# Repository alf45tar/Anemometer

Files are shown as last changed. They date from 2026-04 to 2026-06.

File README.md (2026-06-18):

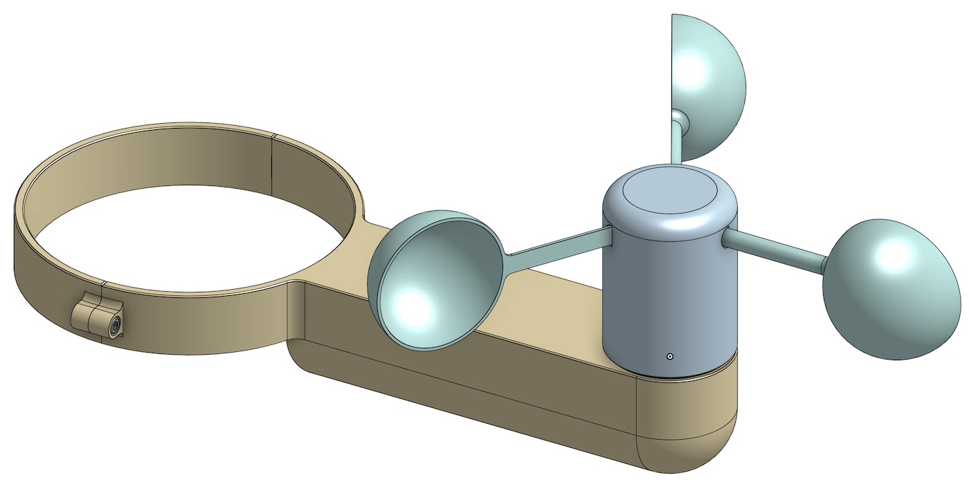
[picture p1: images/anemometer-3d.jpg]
3D Printed Anemometer


# 🌀 ESP32-C6 ULP BLE Anemometer (BTHome V2)

A high-efficiency, battery-powered wind speed sensor (Anemometer) using the ESP32-C6. This project leverages the **ULP (Ultra-Low Power) co-processor** to monitor wind pulses while the main CPU is in Deep Sleep, allowing for years of battery life.

The project uses the LP/ULP core to count anemometer pulses while the main CPU stays in deep sleep, then wakes periodically to compute wind speed and advertise telemetry over BLE using BTHome v2 format.

## 🚀 Key Features

* **Ultra-Low Power:** Can be as low as **\~15µA** in deep sleep on the ESP32-C6 alone. Actual current depends on the board and any attached hardware. The main cores only wake up to calculate and transmit data.
* **BTHome V2 Protocol:** Works natively with **Home Assistant** via Bluetooth—no custom integration or ESPHome YAML required. See [bthome.io](https://bthome.io).
* **Waterproof:** Designed to be waterproof for outdoor use.
* **Temperature Sensor:** Includes the ESP32-C6 internal temperature reading alongside wind speed and battery level telemetry.
* **Intelligent Reporting:**
  * **Wind Detected:** Typically reports on the next 5-second wake cycle while wind is present.
  * **Change Detection:** Tries to report a speed change as soon as it is noticed on the next wake cycle.
  * **Heartbeat:** Sends a periodic "still alive" update, usually about every 60 seconds during calm periods.
* **Hardware Debouncing:** ULP-based software sampling filters out mechanical reed switch "bounce."

## 🎓 What You Can Learn and Reuse in Your Projects

If you are building a similar low-power sensor, these patterns are practical to reuse:

* Keep the main CPU in deep sleep and let the LP/ULP RISC-V core handle pulse counting.
* Wake on a fixed interval, compute pulse delta and wind speed, then advertise only when needed.
* Use BTHome v2 so the sensor works directly with Home Assistant over BLE.
* Add a temperature reading to the same BLE payload so you can track the device environment without extra hardware.
* Add a heartbeat report so the device still publishes when conditions are calm.
* Filter reed-switch bounce in ULP software instead of relying only on hardware.
* Use RTC-capable GPIOs for ULP inputs on ESP32-C6, and avoid strapping pins.
* Add a capacitor across the battery sense divider to stabilize high-impedance ADC readings.
* Keep timing, calibration, BLE, and ADC values in a single header so they are easy to tune.
* Treat wind-speed calibration as a single empirical factor that can be adjusted without changing the rest of the flow.
* Preserve the PlatformIO + ESP-IDF setup and the debug/release sdkconfig defaults for repeatable builds.

## 🛠 Hardware Requirements

1. **ESP32-C6  Board** (e.g., ESP32-C6 Super Mini).
   * For ESP32 and ESP32-S3 boards, check the [ESP32/ESP32-S3](https://github.com/alf45tar/ESP32-ULP-BLE-Anemometer) anemometer project.
2. **Anemometer** (3-cup type with a Reed Switch).
3. **Battery:** Li-ion 18650 or LiPo.

### 📦 Bill of Materials

| Item | Quantity | Notes |
| :--- | :--- | :--- |
| ESP32-C6 Super Mini | 1 | Very cheap and low power board |
| 3D-printed anemometer | 1 | STL files for the [3D-printed parts](https://github.com/alf45tar/Anemometer/tree/main/stl) |
| 608 bearing 8x22x7 mm | 1 | Very common bearing for shaft support |
| M3 heat-set insert | 3 | For connecting the main body to the support and collar |
| M3 hex socket cap screw M3x10 | 3 | Fastens the main body to the support |
| Reed switch | 1 | Wind pulse sensor |
| Magnet 6x3 mm | 2 | For triggering the reed switch |
| O-Ring 8x2 mm | 1 | To seal the base of the rotor and the support |
| Battery | 1 | Li-ion 18650 or LiPo |
| Battery Holder | 1 | |

### 🔌 Wiring

Connect the reed switch between SENSOR_GPIO pin and GND (no need of external pull-up resistor because internal pull-up resistor is used).

```text
  SENSOR_PIN
      |
      |
      +  |
         +--- Reed switch
      +  |
      |
      |
     GND
```

For battery monitoring, a 470 kΩ resistor divider is required.
For stable ADC readings with high-value resistors, place a 0.1uF capacitor from ADC pin to GND.

```text
              BATTERY_ADC_GPIO
                     |
                     |
B+ -----/\/\/\/------+-----/\/\/\/-----+----- GND (B-)
         470k        |      470k       |
                     |                 |
                     +-------||--------+
                            0.1uF
                         (optional)
```

## 💻 Software Requirements

* PlatformIO
* ESP-IDF framework via PlatformIO (already defined in `platformio.ini`)

## 📡 Telemetry Format (BLE)

Advertising payload includes BTHome v2 service data with:

* Packet ID (object id `0x00`)
* Battery percentage (object id `0x01`)
* ESP32-C6 internal temperature in 0.01 °C units (object id `0x02`)
* Wind speed in 0.01 m/s units (object id `0x44`)

Device name in advertisement: `Wind Sensor`

Note: the temperature value is the ESP32-C6 internal chip temperature, not an ambient room sensor. Because the CPU spends most of its time in deep sleep, this reading is typically close to ambient. The internal temperature sensor is configured for a `-10` to `80` °C range.

## ⚙️ Key Tuning Constants

Edit `src/anemometer.h`:

```c
#define SENSOR_PIN 6                        // GPIO used for the anemometer pulse input
                                            // Must be RTC-capable pin: GPIO0-GPIO7 on ESP32-C6
                                            // Avoid GPIO4 and GPIO5 which are used for strapping
#define SLEEP_DURATION 5                    // Deep-sleep interval in seconds between wakeups
#define HEARTBEAT_INTERVAL 60               // Force a periodic telemetry heartbeat every N seconds
#define DEBOUNCE_INTERVAL_CYCLES 1000       // Minimum ULP clock cycles between valid edges to filter out noise (debouncing)

/* Anemometer conversion constants */
#define PULSES_PER_ROTATION 2.0f            // Sensor pulses generated for one full rotor rotation
#define RADIUS 0.078f                       // Rotor radius in meters (center to cup midpoint)
#define CALIBRATION_FACTOR 2.5f             // Empirical multiplier to match real wind speed

/* BLE/BTHome beacon behavior */
#define BLE_ADV_DURATION_MS 1000            // Advertising window duration after each wakeup
#define BLE_ADV_INTERVAL_UNITS 32           // BLE adv interval units (0.625 ms each): 32 = 20 ms

/* Battery measurement via ADC */
#define BATTERY_ADC_GPIO 0                  // GPIO connected to battery sense divider output
                                            // Must be an ADC-capable pin: GPIO0-GPIO6 on ESP32-C6
                                            // Avoid GPIO4 and GPIO5 which are used for strapping
#define BATTERY_ADC_SAMPLES 1               // Number of ADC readings averaged per measurement
#define BATTERY_VOLTAGE_DIVIDER_RATIO 2.0f  // Scale factor from ADC node voltage to battery voltage
#define BATTERY_MIN_MV 3200                 // Battery voltage mapped to 0%
#define BATTERY_MAX_MV 4100                 // Battery voltage mapped to 100%
```

## 🔄 How It Works

1. The main CPU enters deep sleep.
2. LP/ULP firmware monitors the sensor pin (`SENSOR_PIN`) and increments pulse count on valid rising edges.
3. Every wake interval (`SLEEP_DURATION`), the main CPU wakes up.
4. Firmware computes:
   * pulse delta
   * RPM
   * wind speed (m/s and km/h)
   * battery voltage and percentage
   * ESP32-C6 internal temperature
5. BLE advertising is sent when:
   * wind value changed, or
   * heartbeat interval is reached
6. Device returns to deep sleep.

## 📐 Dimensions

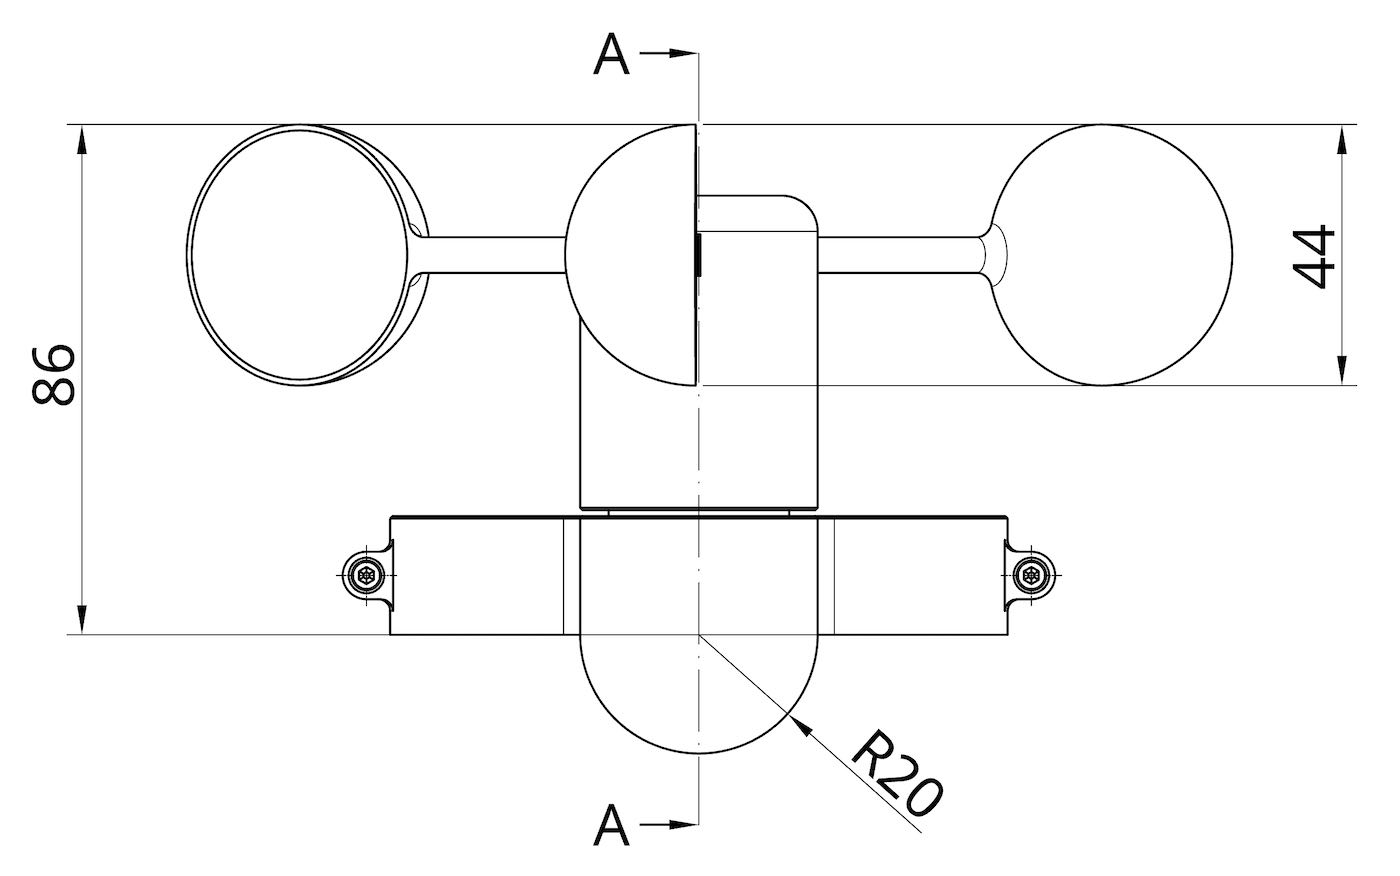
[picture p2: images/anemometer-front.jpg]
Anemometer Front View

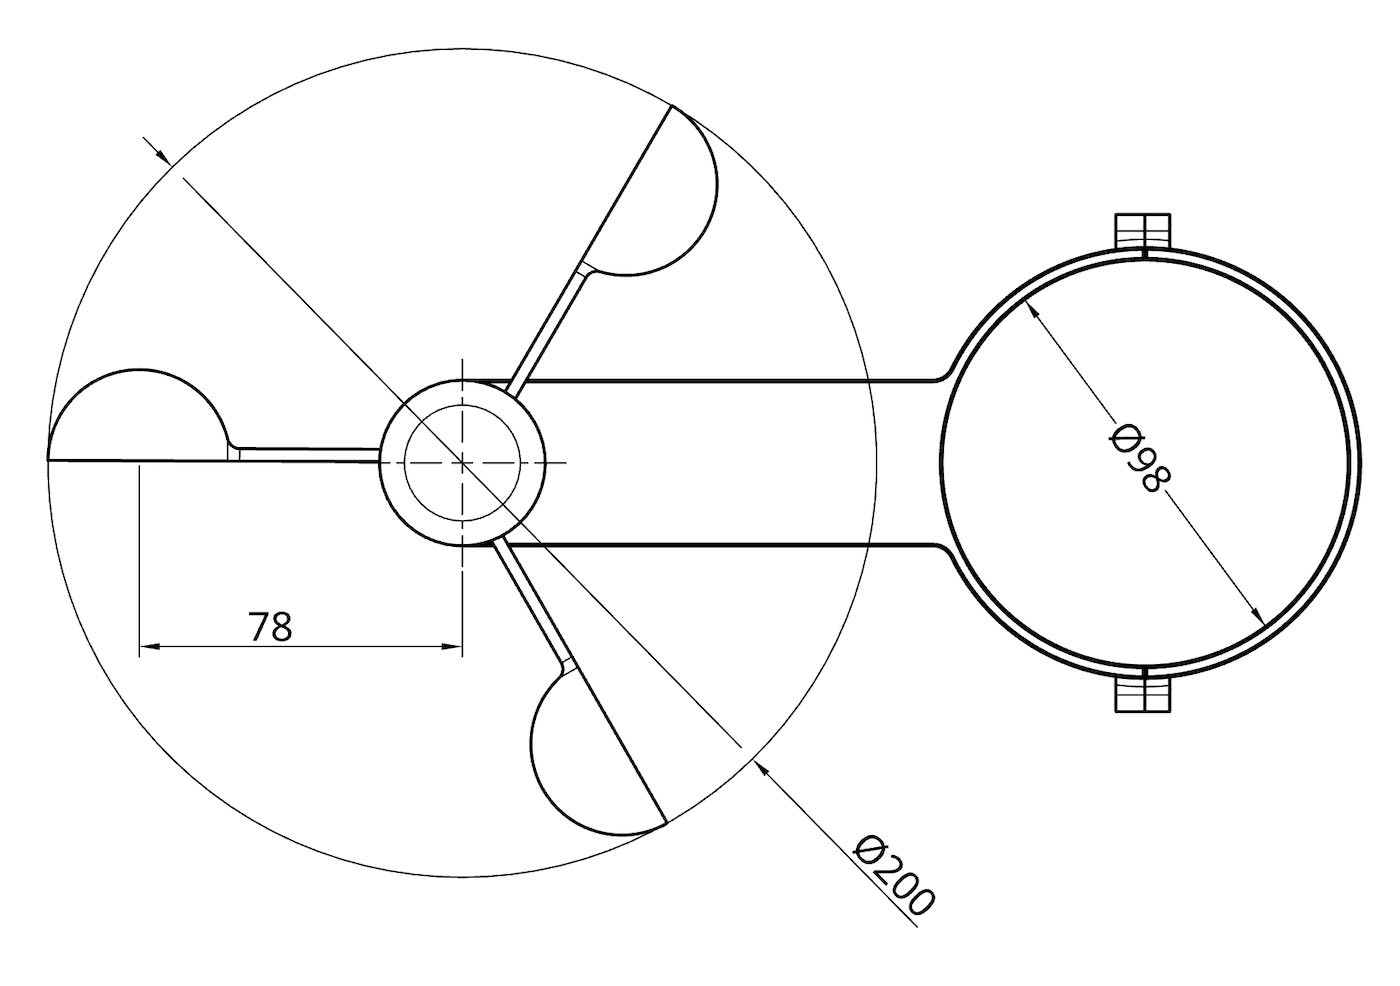
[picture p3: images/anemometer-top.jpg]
Anemometer Top View


## 🧪 Photos

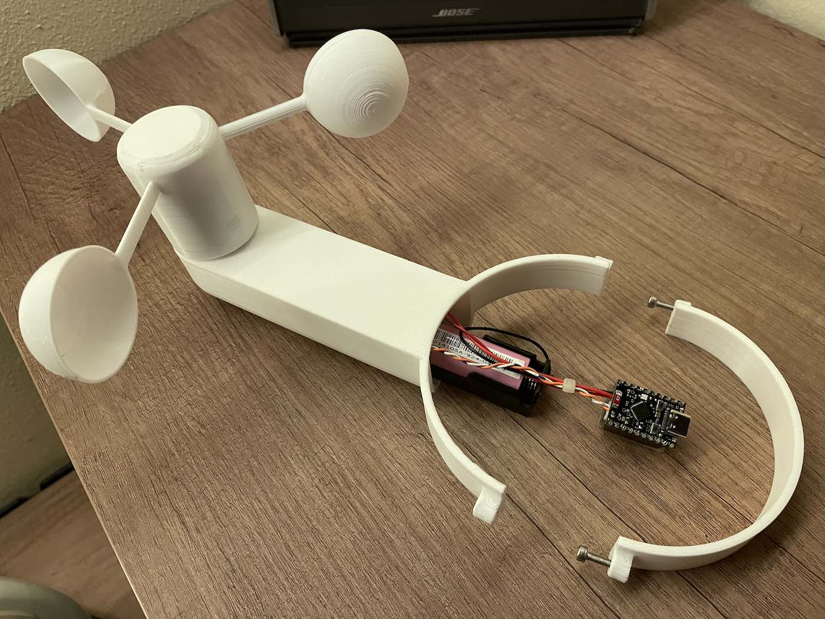
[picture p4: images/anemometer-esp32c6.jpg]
Anemometer ESP32-C6


## 🔌 Shelly Integration

If you are using **Shelly** devices, the anemometer can also be configured as a **virtual component** in your Shelly setup. This does **not** require Home Assistant.

### Example Use Case

Use the anemometer to automatically close an awning with a **Shelly 2PM Gen3** when wind speed gets too high, without any extra wiring between the wind sensor and the Shelly device. The anemometer broadcasts wind data over BLE, and Shelly handles the automation logic on its side.

### ☁️ ThingSpeak Upload Script

The repository also includes [thingspeak-iot.js](thingspeak-iot.js), a separate Shelly script that forwards the latest sensor values to [ThingSpeak](https://thingspeak.mathworks.com).



It samples the configured Shelly components every 5 seconds, keeps the maximum value seen during each 15-second window, and sends one update to ThingSpeak at the end of that window.

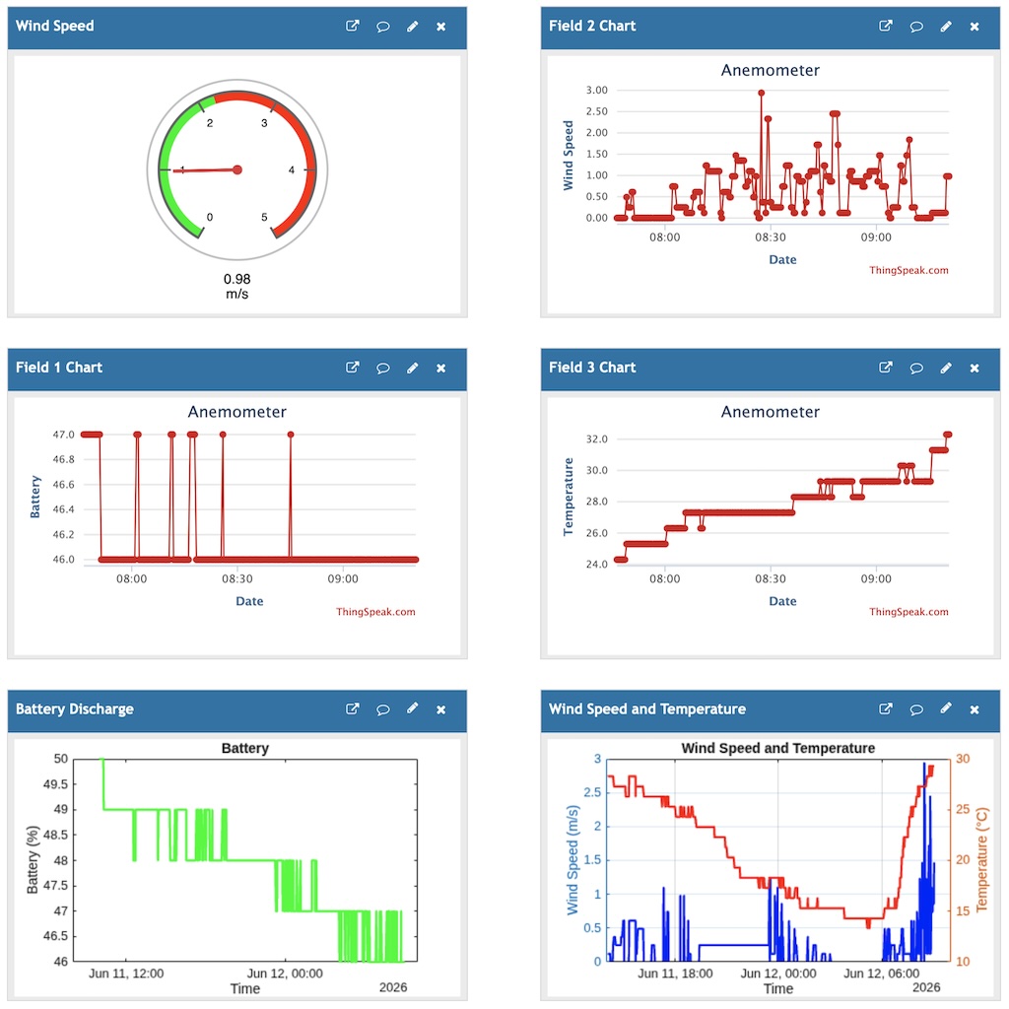
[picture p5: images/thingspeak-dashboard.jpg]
ThingSpeak Dashboard


#### What it sends

* `field1`: battery percentage
* `field2`: wind speed
* `field3`: temperature

#### Setup notes

* Paste the script into a Shelly device that supports JavaScript scripting.
* Set your ThingSpeak Write API Key in `thingspeak-iot.js`.
* Update the component IDs so they match the battery, wind speed, and temperature sensors exposed by your Shelly device.
* The script only uploads when it has collected valid data for the current window.

### ☁️ ThingsBoard Upload Script

The repository also includes [thingsboard-iot.js](thingsboard-iot.js), a Shelly script that forwards sensor data to [ThingsBoard](https://thingsboard.io/).



It samples the configured Shelly components every 5 seconds, keeps the maximum value seen during each 15-second window, and sends one update to ThingsBoard at the end of that window.

#### What it sends

* `battery`: battery percentage
* `wind_speed`: wind speed
* `temperature`: temperature

#### Setup notes

* Paste the script into a Shelly device that supports JavaScript scripting.
* Create a new **Device** in ThingsBoard and obtain the **Device Token**.
* Set your ThingsBoard host and Device Token in `thingsboard-iot.js`:
* Update the component IDs so they match the battery, wind speed, and temperature sensors exposed by your Shelly device.
* The script only uploads when it has collected valid data for the current window.

## 📜 License

This project is licensed under the MIT License - see the LICENSE file for details.

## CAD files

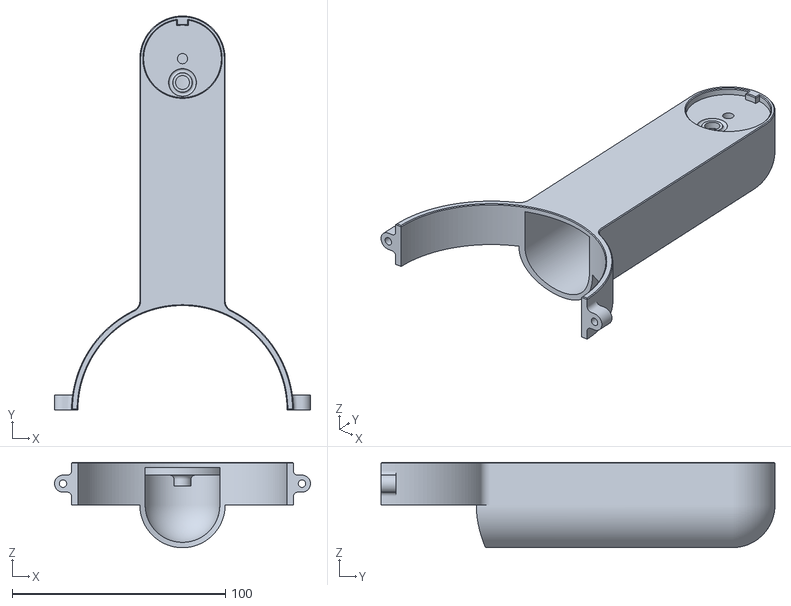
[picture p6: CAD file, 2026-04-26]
stl/Support.stl
120.0 x 184.7 x 40.0

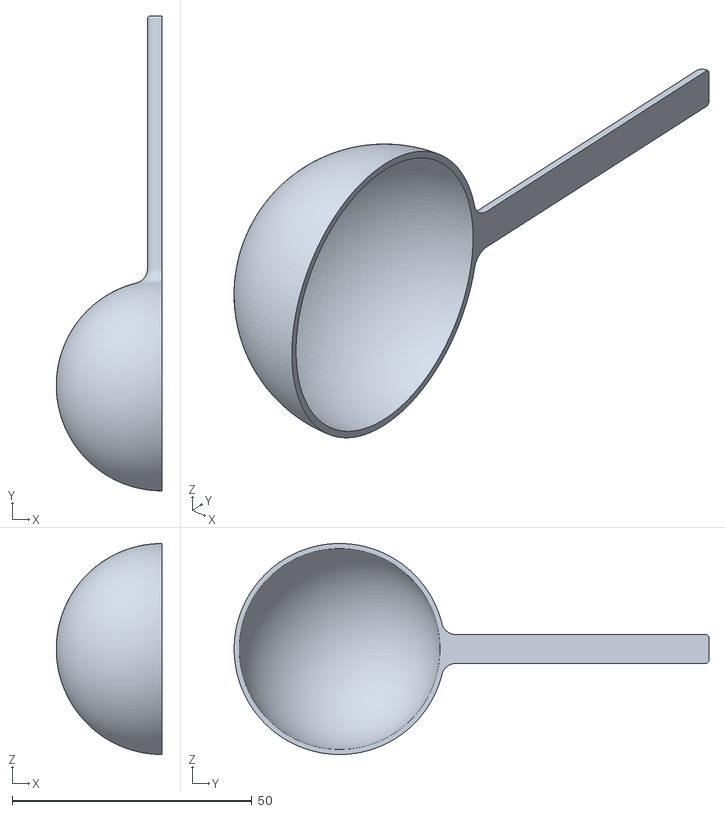
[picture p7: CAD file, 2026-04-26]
stl/Spoon.stl
22.0 x 99.0 x 44.0

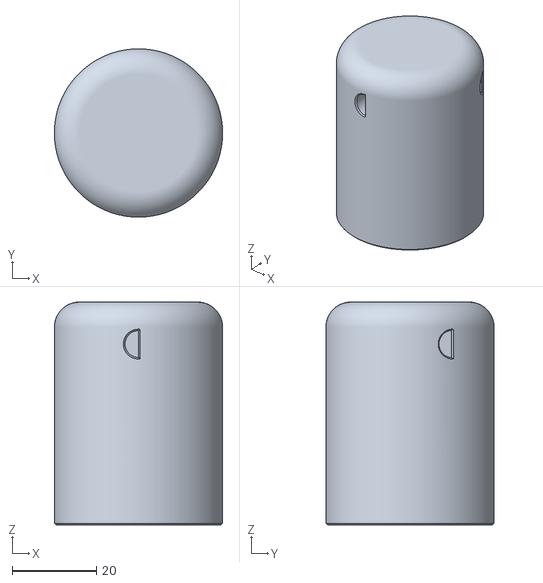
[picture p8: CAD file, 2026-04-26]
stl/Rotor.stl
40.0 x 40.0 x 53.0

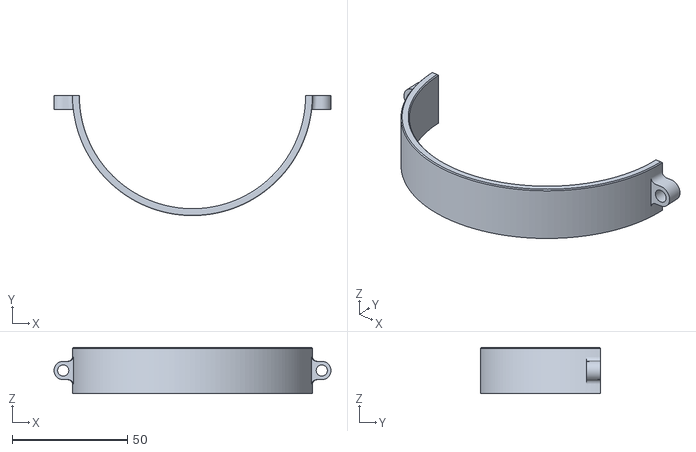
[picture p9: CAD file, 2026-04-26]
stl/Collar.stl
120.0 x 52.0 x 20.0

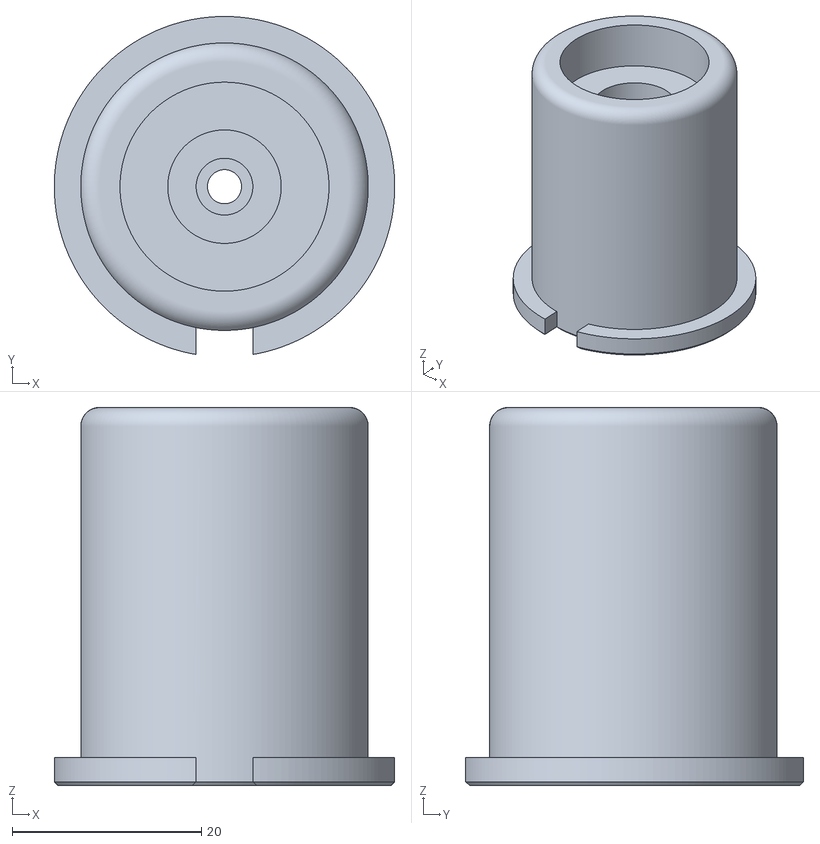
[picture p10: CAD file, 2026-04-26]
stl/Base.stl
36.0 x 35.7 x 40.0

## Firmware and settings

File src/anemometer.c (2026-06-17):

/*
 * ======================================================================================
 * ESP32-C6 ULTRA-LOW POWER (ULP) BLE ANEMOMETER
 * ======================================================================================
 * * DESCRIPTION:
 *    This firmware transforms an ESP32-C6 into a high-efficiency wind speed sensor.
 *    It uses the ULP (Ultra-Low Power) co-processor to count pulses from a reed
 *    switch while the main core are in Deep Sleep.
 * * HOW IT WORKS:
 *    1. SLEEP: The ESP32 enters Deep Sleep (consuming ~10-15µA).
 *    2. ULP MONITORING: The ULP co-processor remains active, using interrupt-driven
 *        edge detection on SENSOR_PIN to detect magnet passes.
 *    3. WAKEUP: Every 5 seconds, the main core wakes up to process the ULP data.
 *    4. LOGIC ENGINE:
 *        - If Wind Speed > 0: Calculates speed and broadcasts immediately via BLE.
 *        - If Speed Changes: Broadcasts immediately to show the change.
 *        - If No Wind: Skips BLE transmission to save battery.
 *        - Heartbeat: Every 60 seconds, it forces a broadcast (even if no wind) so Home
 *          Assistant knows the sensor is still online.
 * * DATA PROTOCOL:
 *    Uses BTHome V2 (Bluetooth Low Energy). Compatible with Home Assistant and Shelly
 * * HARDWARE NOTES:
 *    - SENSOR_PIN must be an RTC-capable pin.
 *    - Pulses: 2 pulses per revolution (assuming 2 magnets).
 *    - Radius: 0.078m (center to cup middle).
 *    - Calibration: 2.5x factor to compensate for cup drag/aerodynamics.
 * * POWER CONSUMPTION:
 *    - Deep Sleep: ~15µA (it depends by the board, less feautures is better)
 *    - BLE Broadcast (1.5s): ~100mA
 *    - Estimated Battery Life (1000mAh Li-ion): >1 year with 1-minute heartbeats.
 * ======================================================================================
 */

#include <stdio.h>
#include <stdbool.h>
#include <inttypes.h>
#include <limits.h>
#include <math.h>
#include "esp_attr.h"
#include "esp_check.h"
#include "esp_log.h"
#include "esp_mac.h"
#include "esp_sleep.h"
#include "driver/gpio.h"
#include "driver/rtc_io.h"
#include "driver/temperature_sensor.h"
#include "freertos/FreeRTOS.h"
#include "freertos/task.h"
#include "nvs_flash.h"
#include "ble_hci.h"
#include "ulp_lp_core.h"
#include "ulp_main.h"
#include "lp_core_uart.h"
#include "anemometer.h"
#include "battery.h"
#include "temperature.h"

extern const uint8_t ulp_main_bin_start[] asm("_binary_ulp_main_bin_start");
extern const uint8_t ulp_main_bin_end[]   asm("_binary_ulp_main_bin_end");

static const char *TAG = "anemometer";


static void init_ulp_program(void);
static void init_ble(float wind_speed_mps, uint8_t battery_percent, int16_t internal_temp_centi, uint8_t packet_id);
static void build_ble_adv(float wind_speed_mps, uint8_t battery_percent, int16_t internal_temp_centi, uint8_t packet_id);

static RTC_DATA_ATTR bool ulp_program_initialized;
static RTC_DATA_ATTR uint32_t last_pulse_count;
static RTC_DATA_ATTR uint32_t heartbeat_elapsed_seconds;
static RTC_DATA_ATTR uint32_t last_advertised_pulse_delta;
static RTC_DATA_ATTR uint8_t bthome_packet_id;

static uint8_t s_adv_data[31];
static uint8_t s_adv_len;

void app_main(void)
{
#if CONFIG_LOG_DEFAULT_LEVEL > 0
    /*
    *   Set default log level to WARN to reduce noise, but set INFO for our tag.
    */
    esp_log_level_set("*", ESP_LOG_WARN);
    esp_log_level_set(TAG, ESP_LOG_INFO);
    /*
    *  If user is using USB-serial-jtag then serial monitor needs some time to
    *  re-connect to the USB port. We wait 3 sec here to allow for it to make the reconnection
    *  before we print anything. Otherwise the chip will go back to sleep again before the user
    *  has time to monitor any output.
    */
    vTaskDelay(pdMS_TO_TICKS(3000));

    ESP_LOGI(TAG, "Main processor will wake every %d seconds", SLEEP_DURATION);

    uint32_t wake_causes = esp_sleep_get_wakeup_causes();

    if (wake_causes & BIT(ESP_SLEEP_WAKEUP_ULP)) {
        ESP_LOGI(TAG, "ULP woke up the main CPU!");
    }

    if (wake_causes & BIT(ESP_SLEEP_WAKEUP_TIMER)) {
        ESP_LOGI(TAG, "Timer woke up the main CPU!");
    }
#endif /* CONFIG_LOG_DEFAULT_LEVEL > 0 */

    /* Load the LP program and initialize NVS flash only once on cold boot */
    if (!ulp_program_initialized) {
        ESP_LOGI(TAG, "Initializing ULP program and Flash...");
        init_ulp_program();
        ulp_program_initialized = true;
        
        /* Initialize NVS once since it doesn't need re-init for pure non-connectable BLE beacons */
        esp_err_t ret = nvs_flash_init();
        if (ret == ESP_ERR_NVS_NO_FREE_PAGES || ret == ESP_ERR_NVS_NEW_VERSION_FOUND) {
            ESP_ERROR_CHECK(nvs_flash_erase());
            ret = nvs_flash_init();
        }
        ESP_ERROR_CHECK(ret);

        /* Baseline on first boot to avoid using stale/uninitialized pulse deltas */
        last_pulse_count = ulp_pulse_count;
        heartbeat_elapsed_seconds = 0;
        last_advertised_pulse_delta = 0;
        bthome_packet_id = 0;
    }

    heartbeat_elapsed_seconds += SLEEP_DURATION;
    uint32_t pulse_delta = ulp_pulse_count - last_pulse_count;
    bool wind_changed = (pulse_delta != last_advertised_pulse_delta);
    bool heartbeat_due = (heartbeat_elapsed_seconds >= HEARTBEAT_INTERVAL);
    bool should_advertise = wind_changed || heartbeat_due;
    uint32_t heartbeat_remaining_s = heartbeat_due ? 0 : (HEARTBEAT_INTERVAL - heartbeat_elapsed_seconds);

    if (should_advertise) {
        /* Compute telemetry only when we are going to advertise */
        float rotations = (float)pulse_delta / PULSES_PER_ROTATION;
        float rps = rotations / (float)SLEEP_DURATION;
        float rpm = rps * 60.0f;
        float wind_speed_mps = rps * (2.0f * 3.14159265358979323846f * RADIUS) * CALIBRATION_FACTOR;
        float wind_speed_kmh = wind_speed_mps * 3.6f;
        uint16_t battery_mv = read_battery_mv(TAG);
        uint8_t battery_percent = battery_mv_to_percent(battery_mv);
        int16_t internal_temp_centi = read_internal_temp_centi(TAG);
        float internal_temp_c = (float)internal_temp_centi / 100.0f;

        /* Print speed if changed. */
        if (wind_changed) {
            ESP_LOGI(TAG,
                    "Pulse count: %"PRIu32" (+%"PRIu32") | RPM: %.1f | Wind: %.2f m/s (%.2f km/h) | Battery: %u mV (%u%%) | Temperature: %.2f °C",
                    ulp_pulse_count,
                    pulse_delta,
                    rpm,
                    wind_speed_mps,
                    wind_speed_kmh,
                    battery_mv,
                    battery_percent,
                    internal_temp_c);
        }

        /* Heartbeat every 60 seconds, if no pulse count changing */
        if (heartbeat_due) {
            ESP_LOGI(TAG,
                    "Heartbeat - Pulse count: %"PRIu32" | RPM: %.1f | Wind: %.2f m/s (%.2f km/h) | Battery: %u mV (%u%%) | Temperature: %.2f °C",
                    ulp_pulse_count,
                    rpm,
                    wind_speed_mps,
                    wind_speed_kmh,
                    battery_mv,
                    battery_percent,
                    internal_temp_c);
        }

        /* Broadcast a BTHome frame as a non-connectable BLE beacon only when needed */
        init_ble(wind_speed_mps, battery_percent, internal_temp_centi, bthome_packet_id);
        bthome_packet_id = (uint8_t)(((uint16_t)bthome_packet_id + 1U) & 0xFFU);

        /* Keep beaconing for a short window before deep sleep */
        vTaskDelay(pdMS_TO_TICKS(BLE_ADV_DURATION_MS));

        /* Stop advertising before sleeping */
        ESP_ERROR_CHECK(ble_hci_set_adv_enable(false));
        ESP_ERROR_CHECK(ble_hci_deinit());

        /* Baselines must be updated at the end of the math transmission cycle, 
         * regardless of whether it was triggered by a heartbeat or a true wind shift.
         */
        last_pulse_count = ulp_pulse_count;
        last_advertised_pulse_delta = pulse_delta;
        heartbeat_elapsed_seconds = 0;
    } else {
        ESP_LOGI(TAG,
                 "Pulse count: %"PRIu32" (no change) | Heartbeat in %"PRIu32"s | Wind unchanged | skipping BLE advertising",
                 ulp_pulse_count,
                 heartbeat_remaining_s);
    }
#if CONFIG_LOG_DEFAULT_LEVEL > 0
    /* Go back to sleep, only the ULP will run */
    ESP_LOGI(TAG, "Entering in deep sleep");

    /* Small delay to ensure the messages are printed */
    vTaskDelay(pdMS_TO_TICKS(500));
#endif /* CONFIG_LOG_DEFAULT_LEVEL > 0 */

    ESP_ERROR_CHECK(esp_sleep_enable_ulp_wakeup());
    ESP_ERROR_CHECK(esp_sleep_enable_timer_wakeup(SLEEP_DURATION * 1000000ULL));

    esp_deep_sleep_start();
}

static void init_ble(float wind_speed_mps, uint8_t battery_percent, int16_t internal_temp_centi, uint8_t packet_id)
{
#if CONFIG_LOG_DEFAULT_LEVEL > 0
    uint8_t ble_addr[6] = {0};
    if (esp_read_mac(ble_addr, ESP_MAC_BT) == ESP_OK) {
        ESP_LOGI(TAG,
                 "BLE MAC: %02X:%02X:%02X:%02X:%02X:%02X",
                 ble_addr[0], ble_addr[1], ble_addr[2], ble_addr[3], ble_addr[4], ble_addr[5]);
    } else {
        ESP_LOGW(TAG, "Unable to read BLE MAC");
    }
#endif /* CONFIG_LOG_DEFAULT_LEVEL > 0 */

    ESP_ERROR_CHECK(ble_hci_init());

    build_ble_adv(wind_speed_mps, battery_percent, internal_temp_centi, packet_id);

    ble_hci_adv_param_t adv_param = {
        .adv_int_min = BLE_ADV_INTERVAL_UNITS,                  /* Sets the minimum and maximum time between advertisements */
        .adv_int_max = BLE_ADV_INTERVAL_UNITS,                  /* Setting them to the same value creates a fixed advertising interval */
        .adv_type = ADV_TYPE_NONCONN_IND,                       /* Non-connectable undirected advertising (beacon mode) */
        .own_addr_type = BLE_ADDR_TYPE_PUBLIC,                  /* Use public MAC address for better compatibility */
        .peer_addr = {0},                                       /* Not used in non-connectable mode, but set to zero just in case */
        .peer_addr_type = BLE_ADDR_TYPE_PUBLIC,                 /* Not used in non-connectable mode, but set to public just in case */
        .channel_map = ADV_CHNL_ALL,                            /* Advertise on all channels (37, 38, 39) for best discoverability */
        .adv_filter_policy = ADV_FILTER_ALLOW_SCAN_ANY_CON_ANY, /* Allow all scan and connection requests (though we won't accept connections in non-connectable mode) */
    };

    ESP_ERROR_CHECK(ble_hci_set_adv_param(&adv_param));
    ESP_ERROR_CHECK(ble_hci_set_adv_data(s_adv_len, s_adv_data));
    ESP_ERROR_CHECK(ble_hci_set_adv_enable(true));
    ESP_LOGI(TAG, "BLE HCI advertising started");
}

static void build_ble_adv(float wind_speed_mps, uint8_t battery_percent, int16_t internal_temp_centi, uint8_t packet_id)
{
    uint8_t *cursor = s_adv_data;
    static const uint8_t adv_name[] = {
        'W', 'i', 'n', 'd', ' ', 'S', 'e', 'n', 's', 'o', 'r'
    };
    const uint8_t adv_name_len = (uint8_t)sizeof(adv_name);

    if (wind_speed_mps < 0.0f) {
        wind_speed_mps = 0.0f;
    }

    uint32_t speed_x100 = (uint32_t)lroundf(wind_speed_mps * 100.0f);
    if (speed_x100 > UINT16_MAX) {
        speed_x100 = UINT16_MAX;
    }

    uint8_t battery_payload = battery_percent;

    uint8_t temperature_payload[2] = {
        (uint8_t)(internal_temp_centi & 0xFF),
        (uint8_t)((internal_temp_centi >> 8) & 0xFF),
    };
    uint8_t speed_payload[2] = {
        (uint8_t)(speed_x100 & 0xFF),
        (uint8_t)((speed_x100 >> 8) & 0xFF),
    };

    /* GAP flags: general discoverable + BR/EDR not supported. */
    *cursor++ = 0x02;
    *cursor++ = 0x01;
    *cursor++ = 0x06;

    /* BTHome service data AD structure: len, type, UUID (0xFCD2), device info. */
    *cursor++ = 0x0E;
    *cursor++ = 0x16;
    *cursor++ = 0xD2;
    *cursor++ = 0xFC;
    *cursor++ = 0x40;

    /* Packet ID = object ID 0x00, 1 byte value. */
    *cursor++ = 0x00;
    *cursor++ = packet_id;

    /* Battery = object ID 0x01, 1 byte value. */
    *cursor++ = 0x01;
    *cursor++ = battery_payload;

    /* Temperature = object ID 0x02, 2 bytes little-endian in 0.01 degC units. */
    *cursor++ = 0x02;
    *cursor++ = temperature_payload[0];
    *cursor++ = temperature_payload[1];

    /* Speed = object ID 0x44, 2 bytes little-endian in 0.01 m/s units. */
    *cursor++ = 0x44;
    *cursor++ = speed_payload[0];
    *cursor++ = speed_payload[1];

    /* Complete Local Name AD structure at the end. */
    *cursor++ = (uint8_t)(1 + adv_name_len);
    *cursor++ = 0x09;
    for (uint8_t i = 0; i < adv_name_len; i++) {
        *cursor++ = adv_name[i];
    }

    s_adv_len = (uint8_t)(cursor - s_adv_data);

#if CONFIG_LOG_DEFAULT_LEVEL > 0
    if (esp_log_level_get(TAG) >= ESP_LOG_INFO) {
        char hex_line[(31 * 3) + 1] = {0};
        size_t pos = 0;
        for (uint8_t i = 0; i < s_adv_len; i++) {
            int written = snprintf(&hex_line[pos], sizeof(hex_line) - pos, "%02X%s",
                                s_adv_data[i],
                                (i + 1U < s_adv_len) ? " " : "");
            if (written <= 0) {
                break;
            }
            pos += (size_t)written;
            if (pos >= sizeof(hex_line)) {
                break;
            }
        }
        ESP_LOGI(TAG, "BTHome V2 payload (%d bytes, packet id %u): %s", s_adv_len, packet_id, hex_line);
    }
#endif /* CONFIG_LOG_DEFAULT_LEVEL > 0 */
}

static void init_ulp_program(void)
{
    /* Initialize selected GPIO as RTC IO, enable input, enable pullup, disable pulldown */
    rtc_gpio_init(SENSOR_PIN);
    rtc_gpio_set_direction(SENSOR_PIN, RTC_GPIO_MODE_INPUT_ONLY);
    rtc_gpio_pullup_en(SENSOR_PIN);
    rtc_gpio_pulldown_dis(SENSOR_PIN);

    ESP_ERROR_CHECK(ulp_lp_core_load_binary(ulp_main_bin_start, (ulp_main_bin_end - ulp_main_bin_start)));

    /* Start the program */
    ulp_lp_core_cfg_t cfg = {
        .wakeup_source = ULP_LP_CORE_WAKEUP_SOURCE_HP_CPU,
    };

    ESP_ERROR_CHECK(ulp_lp_core_run(&cfg));
}

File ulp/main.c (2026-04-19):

/*
 * ======================================================================================
 * ESP32-C6 ULP PULSE COUNTER FOR ANEMOMETER
 * ======================================================================================
 * This program runs on the LP/ULP core while the main CPU is in deep sleep.
 *
 * Function overview:
 * 1. Configure a GPIO rising-edge interrupt on the anemometer sensor pin.
 * 2. On each interrupt, apply a short debounce filter to reject false edges.
 * 3. Increment pulse_count for valid pulses so the main firmware can compute
 *    rotational speed and wind speed when it wakes up.
 * 4. Stay in an interrupt wait state between pulses to minimize power use.
 * ======================================================================================
 */

#include <stdint.h>
#include <stdbool.h>
#include "sdkconfig.h"
#include "ulp_lp_core.h"
#include "ulp_lp_core_utils.h"
#include "ulp_lp_core_gpio.h"
#include "ulp_lp_core_interrupts.h"
#include "riscv/csr.h"
#include "../src/anemometer.h"


uint32_t pulse_count;
static uint32_t last_trigger_time_cycles;


void LP_CORE_ISR_ATTR ulp_lp_core_lp_io_intr_handler(void)
{
    ulp_lp_core_gpio_clear_intr_status();
    uint32_t trigger_time_cycles = RV_READ_CSR(mcycle);
    /* Do some simple debouncing, do not count spurious pulses */
    if (trigger_time_cycles - last_trigger_time_cycles > DEBOUNCE_INTERVAL_CYCLES) {
        pulse_count++;
        last_trigger_time_cycles = trigger_time_cycles;
    }
}



int main (void)
{
    ulp_lp_core_intr_enable();
    ulp_lp_core_gpio_intr_enable(SENSOR_PIN, GPIO_INTR_POSEDGE);

    while(1) {

        /* Put CPU into a wait state to reduce power consumption while waiting for pulses */
        ulp_lp_core_wait_for_intr();

    }

    return 0;
}

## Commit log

2026-04-19 Refactor anemometer project structure and update configurations
    - Cleaned up CMakeLists.txt files to streamline component registration and build settings.
    - Enhanced sdkconfig.defaults by removing unnecessary Bluetooth configuration.
    - Added detailed documentation comments in anemometer.c and main.c for clarity on functionality.
    - Updated anemometer.h with additional constants for debounce intervals and rotor specifications.
    - Introduced idf_component.yml to manage dependencies for the BLE HCI component.
2026-04-26 Add README and initial project files for ESP32-C6 ULP BLE Anemometer
    [Base.stl, Collar.stl, Rotor.stl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]
2026-04-26 Enhance README: expand project reuse patterns, improve section headings, and clarify ADC resistor values
2026-04-26 Update README: clarify link to STL files for 3D-printed anemometer parts
2026-04-26 Update README: clarify link to ESP32/ESP32-S3 anemometer project in hardware requirements
2026-04-26 Update README: add waterproof feature and O-ring requirement for rotor assembly
2026-04-27 Enhance anemometer functionality: add internal temperature reading and update BLE advertisement to include temperature data
2026-04-27 Enhance anemometer functionality: add internal temperature reading and update temperature sensor range
2026-04-28 Update README: include internal temperature sensor details and BLE payload enhancements
2026-06-17 Implement battery voltage interpolation
2026-06-18 Add ThingsBoard upload script for sensor data transmission
